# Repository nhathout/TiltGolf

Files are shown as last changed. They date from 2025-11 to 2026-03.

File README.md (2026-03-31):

<p align="center">
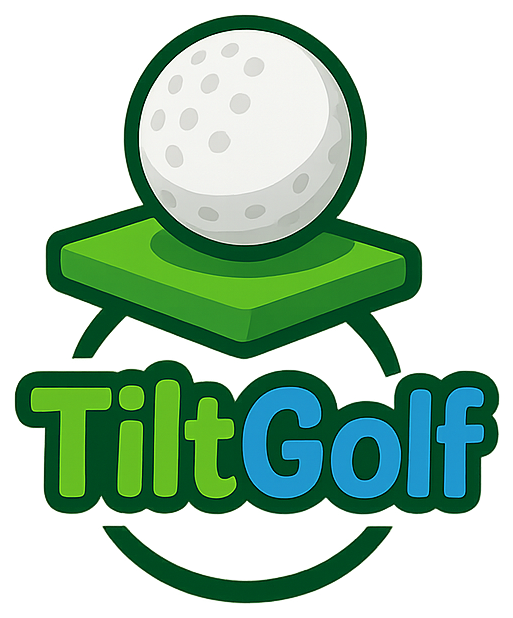
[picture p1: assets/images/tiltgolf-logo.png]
TiltGolf logo
  
</p>

TiltGolf is a tilt-controlled golf game that runs on a BeagleBone with an attached LCD. An IMU senses tilt and a kernel-space driver streams those readings to the Qt game. The UI presents arcade-style menus and levels, while the physics layer keeps the golf ball rolling realistically around the different levels.

## Demo
<p align="center">
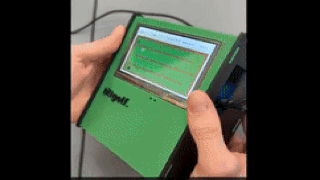
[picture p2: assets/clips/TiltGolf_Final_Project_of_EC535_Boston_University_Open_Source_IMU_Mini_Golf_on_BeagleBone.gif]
TiltGolf gameplay demo
  
</p>

<p align="center">
  <a href="assets/clips/TiltGolf%20%E2%80%94%20Final%20Project%20of%20EC535%20%40%20Boston%20University%20_%20Open-Source%20IMU%20Mini%20Golf%20on%20BeagleBone.mp4">View the full MP4 demo</a>
</p>

## Project Links
- YouTube demo: https://www.youtube.com/watch?v=vEOcKTJfxNo
- Final report (PDF): https://github.com/nhathout/TiltGolf/blob/main/tiltgolf-final-report.pdf
- Progress presentation (PDF): https://github.com/nhathout/TiltGolf/blob/main/assets/progress-presentation/TiltGolf_%20Project%20Progress.pdf

## Hardware & Software Stack
- **BeagleBone Black + LCD cape** – what the game renders on.
- **Custom IMU module** – `IMU.*` and the kernel driver provide filtered tilt angles.
- **Qt 5 widgets UI** – `main.cpp`, `MainWindow`, `MenuScreen`, and `GameScreen` deliver the UX optimized for touch.
- **Physics layer** – `PhysicsEngine.*`, `GameController.*`, and `GameView.*` synchronize IMU input with Box2D-style ball motion.

## Building the Qt Application
The checked-in `Makefile` was generated by `qmake` for the EC535 BeagleBone cross toolchain. If you are on that toolchain:

```bash
cd tiltgolf
make          # uses qmake-generated rules and the arm-linux-g++ compiler
```

For native desktop experimentation you can regenerate host build files:

```bash
cd tiltgolf
qmake tiltgolf.pro
make
./tiltgolf    # runs the Qt UI on your workstation
```

> ℹ️  Ensure Qt 5.15 (or later) development packages and a C++17-capable compiler are installed.

## Prebuilt BeagleBone Binary
- `tiltgolf/tiltgolf_final` is the ready-to-run executable for the BeagleBone + IMU + LCD setup if you prefer not to run `make`.
- Copy to the board and run it.

## Box2D Test (runs on Mac)
The `Box2DTest.cpp` file is a lightweight SFML window that drives a Box2D world for tuning forces, damping, and collisions before pushing to hardware.

### Prerequisites
- Box2D 3.x headers/libraries available on your system (e.g., via package manager).
- SFML 2.5+ development packages (`sfml-graphics`, `sfml-window`, `sfml-system`).

### Build & Run the Test
```bash
mkdir -p build
g++ -std=c++17 tiltgolf/Box2DTest.cpp -I/usr/include -o build/Box2DTest \
    $(pkg-config --cflags --libs sfml-graphics sfml-window sfml-system box2d)

./build/Box2DTest
```

## Screens & Levels
<table>
  <tr>
    <td>Main menu</td>
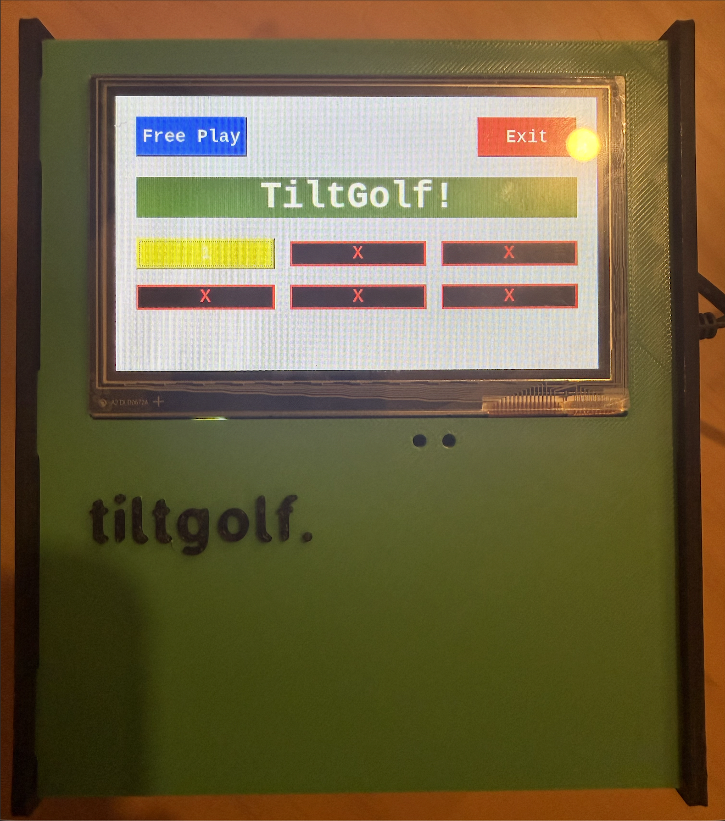
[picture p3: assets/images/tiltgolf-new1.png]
TiltGolf menu mock
    <td></td>
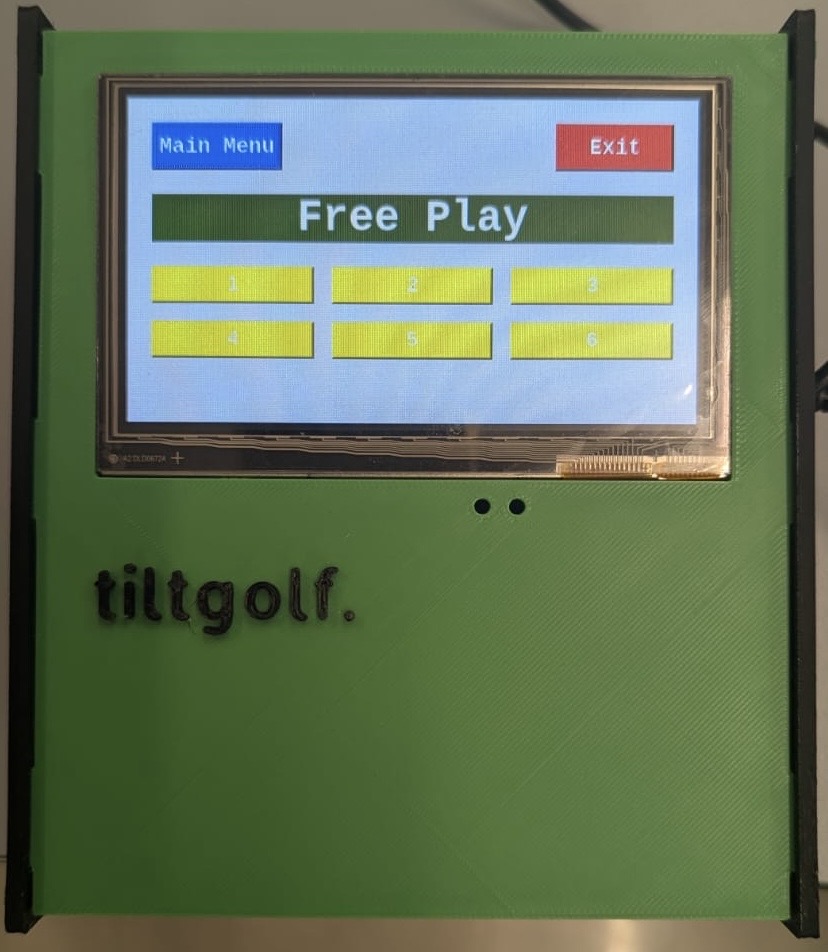
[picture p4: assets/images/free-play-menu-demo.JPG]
Free play menu
    <td></td>
  </tr>
  <tr>
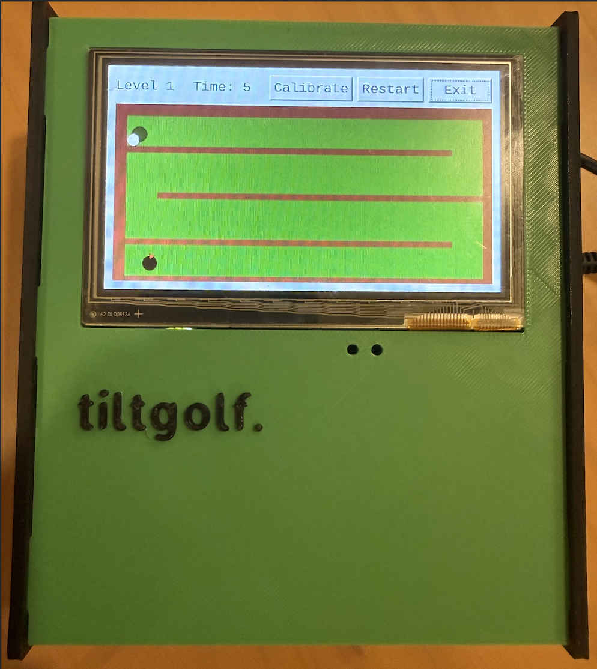
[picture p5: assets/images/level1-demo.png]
Level 1
    <td></td>
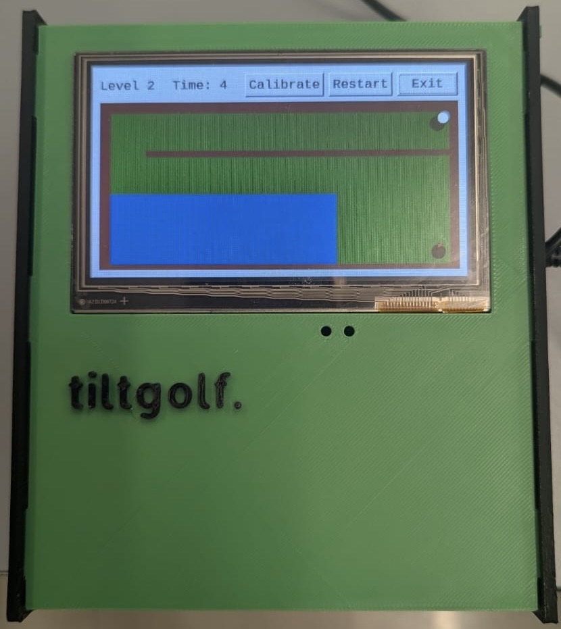
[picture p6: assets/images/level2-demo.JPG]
Level 2
    <td></td>
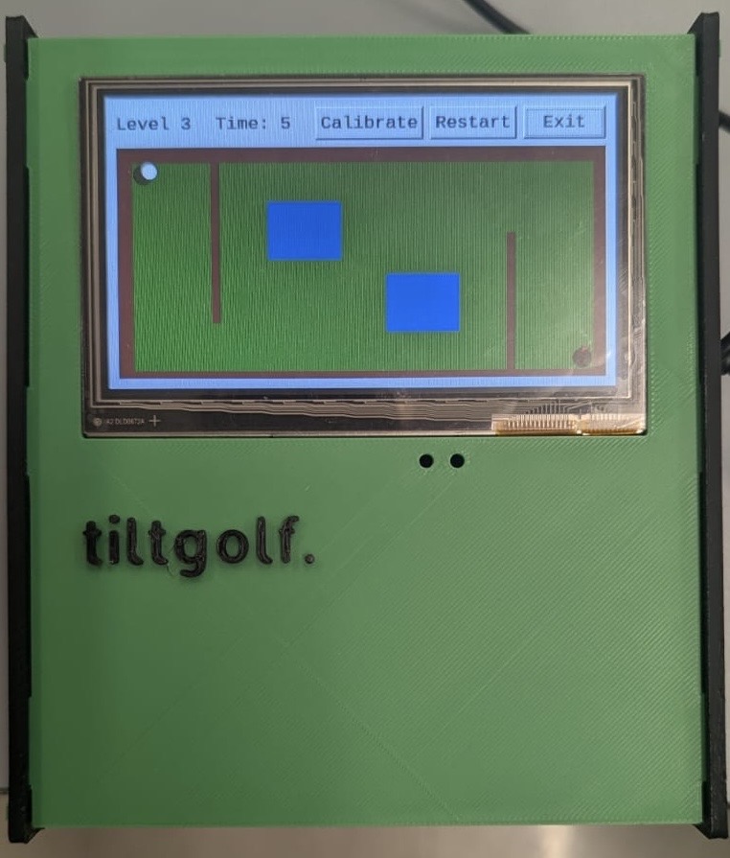
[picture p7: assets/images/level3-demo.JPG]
Level 3
    <td></td>
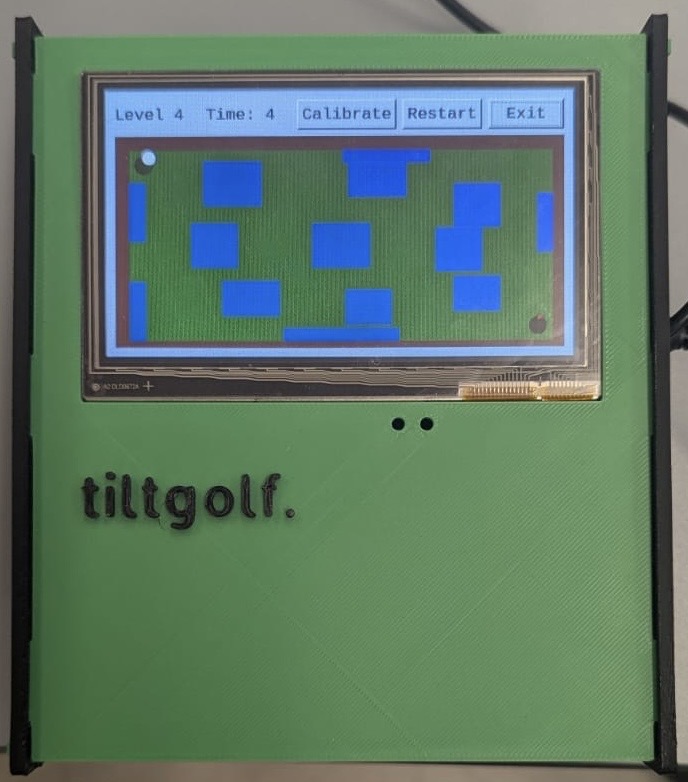
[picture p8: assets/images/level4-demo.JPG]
Level 4
    <td></td>
  </tr>
  <tr>
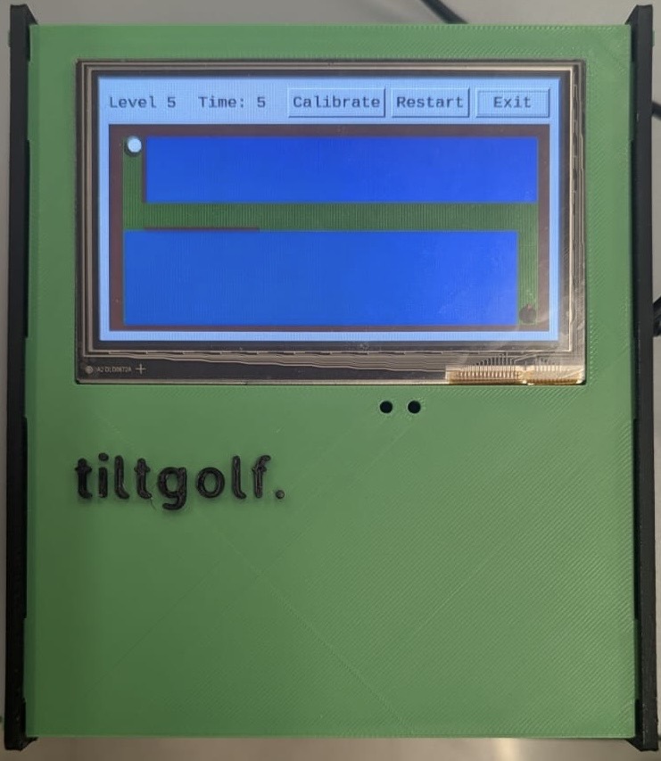
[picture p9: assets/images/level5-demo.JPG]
Level 5
    <td></td>
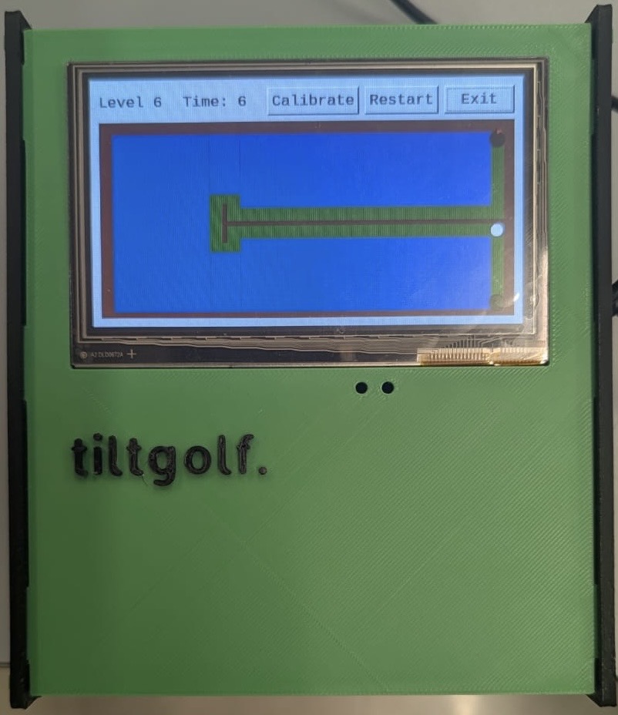
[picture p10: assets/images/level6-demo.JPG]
Level 6
    <td></td>
  </tr>
</table>

## Hardware
<table>
  <tr>
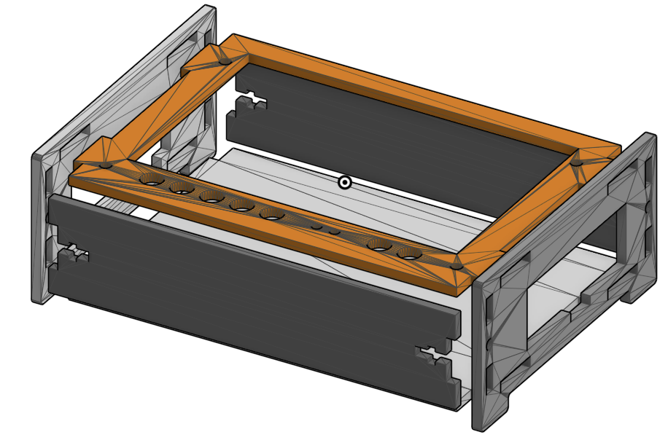
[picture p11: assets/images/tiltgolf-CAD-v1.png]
TiltGolf CAD v1
    <td></td>
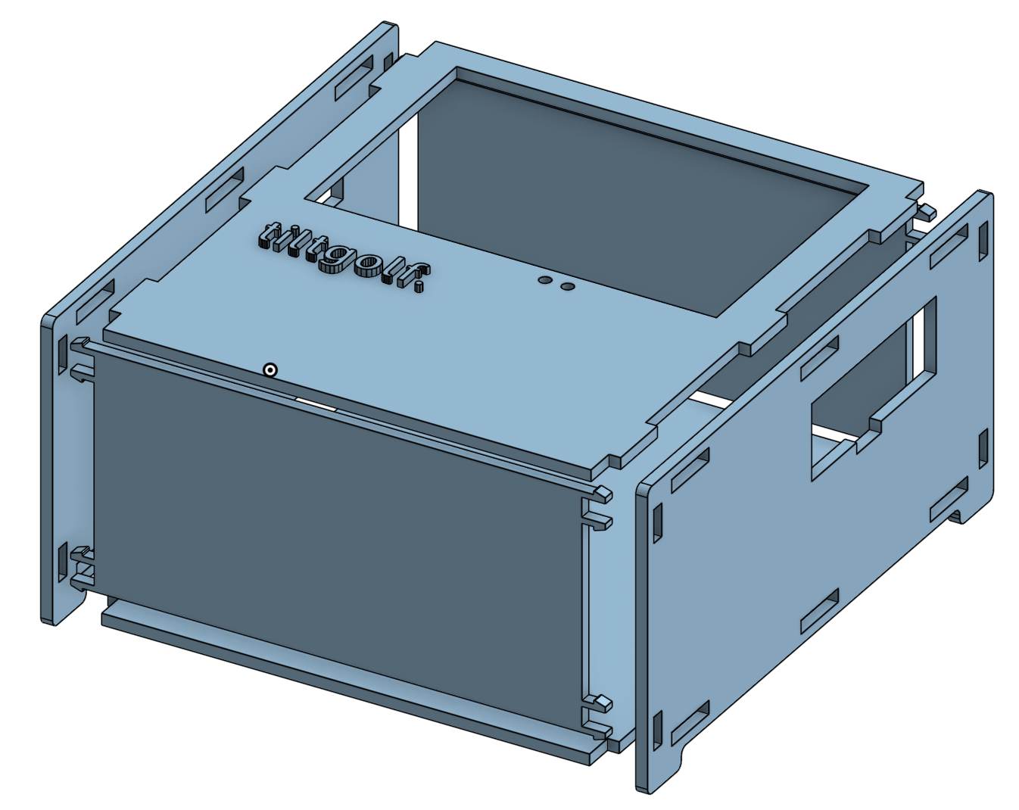
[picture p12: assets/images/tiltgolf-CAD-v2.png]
TiltGolf CAD v2
    <td></td>
  </tr>
</table>

## Physics Engine Test
<p>
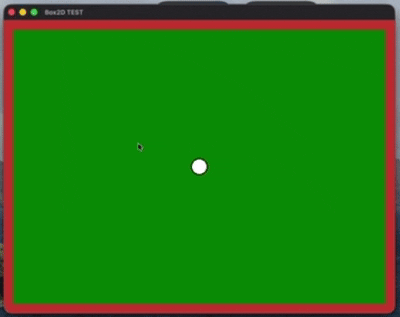
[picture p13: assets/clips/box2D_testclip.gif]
Box2D physics engine test
  
</p>

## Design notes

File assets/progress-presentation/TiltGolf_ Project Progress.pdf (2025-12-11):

# TiltGolf: Tilt-Controlled Golf Game on a BeagleBone

## Team TiltGolf

## Noah Hathout (nhathout@bu.edu), Bennett Taylor (betaylor@bu.edu), Skanda Nadig(skandan@bu.edu)

## Motivation and Project Idea

- Problem: Create a fun, interactive game that uses simulated real-world physics without relying on buttons, joysticks, or keyboard inputs. We also want to make this module as polished as possible with a custom 3D printed enclosure and fun level design.
- Who Cares? Students and/or instructors in embedded systems could use the game as a fun demo of kernel modules and divers + real-time graphics and simulated physics. Kids would also have a lot of fun playing a “GameBoy”-like game that is both challenging and fulfilling.
- Main Project Idea:
- Golf game running entirely on Breaglebone + LCD cape; 3D printed handheld enclosure with built-in IMU for tilt sensing; Qt UI + physics engine that make gameplay smooth and realistic.

## 3D Printed Enclosure Inspiration

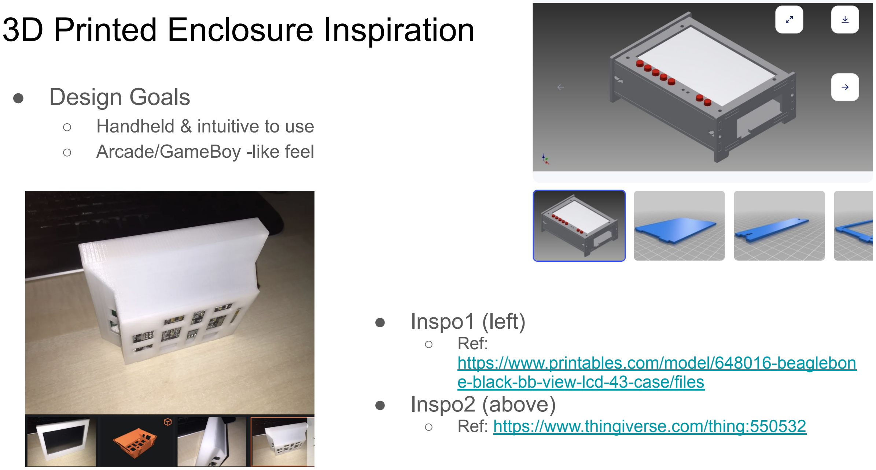
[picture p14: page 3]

- Design Goals
- Handheld & intuitive to use
- Arcade/GameBoy -like feel
- Inspo1 (left)
- Ref:
https://www.printables.com/model/648016-beaglebone-black-bb-view-lcd-43-case/files (https://www.printables.com/model/648016-beaglebone-black-bb-view-lcd-43-case/files)
- Inspo2 (above)
- Ref: https://www.thingiverse.com/thing:550532

## Project Description

- Summary:
TiltGolf is a tilt-controlled golf game that runs on a BeagleBone Black with an attached LCD cape. Also in the enclosure will be an IMU that senses the device’s tilt. This tilt will be filtered in the kernel-space and fed to the Qt-based game. The layer that takes care of the physics engine is based on Box2D with realistic physics and acceleration properties so that the ball rolls, slows down, and bounces off walls realistically as the player tils the device. QT is used to handle menuing, LCD user input, and rendering the Box2D golf simulation.

## System Architecture

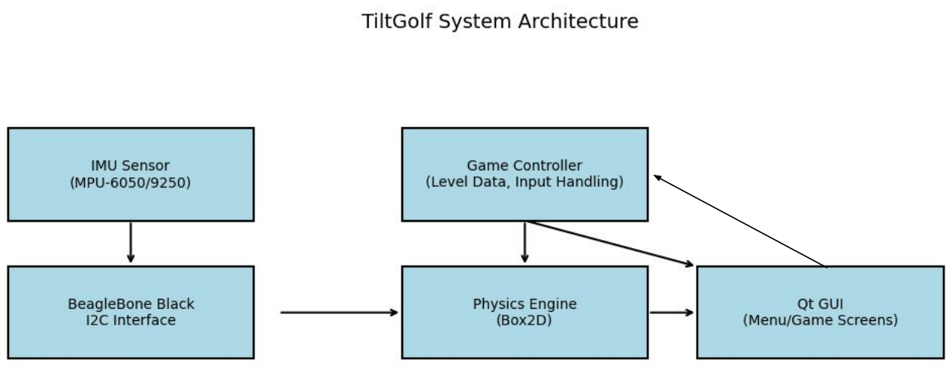
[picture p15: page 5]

5. Physics Engine
a. Box2D used for realistic ball movement and collision detection
b. Physics engine updates ball state each frame
c. Integrated into the game binary (statically linked)

## System Components

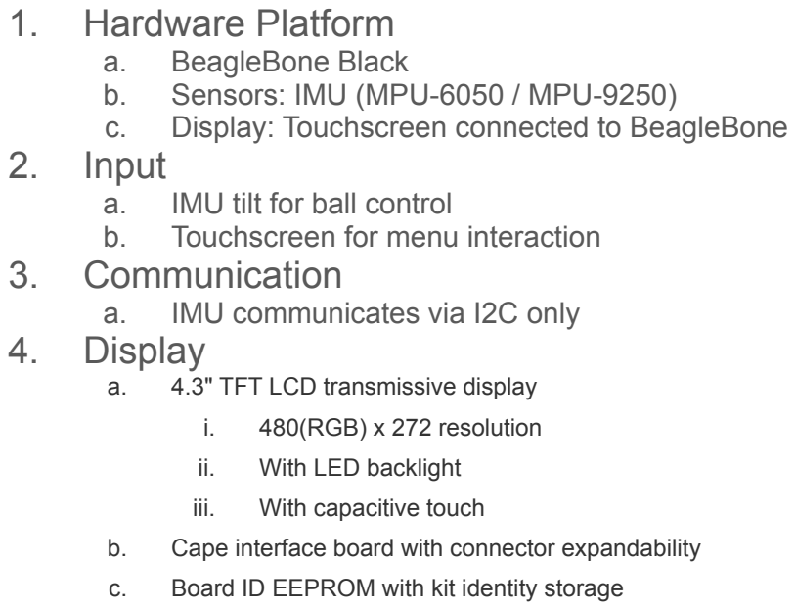
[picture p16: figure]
1. Hardware Platform; a. BeagleBone Black b. Sensors: IMU (MPU-6050 / MPU-9250); 2. Input; a. IMU tilt for ball control b. Touchscreen for menu interaction 3. Communication; a. IMU communicates via I2C only 4. Display; a. 4.3" TFT LCD transmissive display; i. 480(RGB) x 272 resolution; With LED backlight; iii.; With capacitive touch

c. Display: Touchscreen connected to BeagleBone
b. Cape interface board with connector expandability
c. Board ID EEPROM with kit identity storage

## System Components

5. Physics Engine
a. Box2D used for realistic ball movement and collision detection
b. Physics engine updates ball state each frame
c. Integrated into the game binary (statically linked)
6. Rendering
a. Qt GUI for all game screens and visual updates
b. Game loop:
i. Choose level → Start simulation → Read IMU → Update Physics → Render Screen → Repeat → Exit or Restart
7. Output / Audio
a. Visual output only (Qt GUI)
b. No audio output

## Milestones, timeline, and breakdown of tasks

- Creation of level data, game loop, and leaderboard
- Assigned to: Bennett Taylor
- Complete by: December 3rd
- Progress: Level start and restart have been completed
- Leaderboard and separate users is “nice to have”
- Integration of level data and Box2D simulation
- Assigned to: Noah Hathout
- Complete by: December 6th
- Progress: Box2D simulation framework has been established
- Integration of menuing and Box2D simulation rendering
- Assigned to: Bennett Taylor
- Complete by: November 31st
- Progress: Menuing and Box2D rendering have both been completed
- Integration of IMU output and Box2D simulation
- Assigned to: Skanda Nadig
- Complete by: December 3rd
- Progress: IMU output is being read and Box2D simulation is in working order

Work Package | Nov | Nov | Nov | Nov | Nov | Dec | Dec | Dec
1.0. Planning | Design | Implementation | | Test, Debug, Improve
2.0. Screen Design | Design | Implementation | | Test, Debug, Improve
3.0. Sensor testing | Tech. Req. Definition | Test, Debug, Improve
4.0. Hardware integration | Design | Implement logic | | Test, Debug, Improve
5.0 Game Physics Box2D | Plan & Design | Implement logic | Integrate with screen & hardware
6.0 Report | | Structure | | Write-up Editing
7.0. Presentation | | | | Structure | Content

## Box2D Physics Engine Test

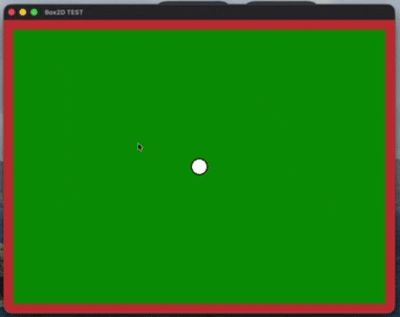
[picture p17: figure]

Here is a clip showing a golf
ball working with the Box2D
physics engine in a simple 4-wall map. This was our
proof-of-concept (running on a Mac with arrow key inputs) that now allows us to use the
physics on the hardware and create new levels and maps.

## IMU sensor(MPU-6050 / MPU-9250)

1. Purpose:
a. Measures device orientation (tilt along X, Y, Z axes)
b. Provides accelerometer and gyroscope data for game input
2. Connection:
a. Connected to BeagleBone Black via I2C interface
3. Data Acquisition:
a. Registers used:
i. Accelerometer: ACCEL_XOUT_H/L, ACCEL_YOUT_H/L, ACCEL_ZOUT_H/L
ii. | Gyroscope: GYRO_XOUT_H/L, GYRO_YOUT_H/L, GYRO_ZOUT_H/L
iii. | Configuration: PWR_MGMT_1, CONFIG, etc.
4. Reading values:
a. Using I2C commands (i2cget, i2c-tools) or hexdump for debugging
b. Example: i2cget -y 1 0x68 0x3B to read ACCEL_X register

## IMU sensor Pin layout

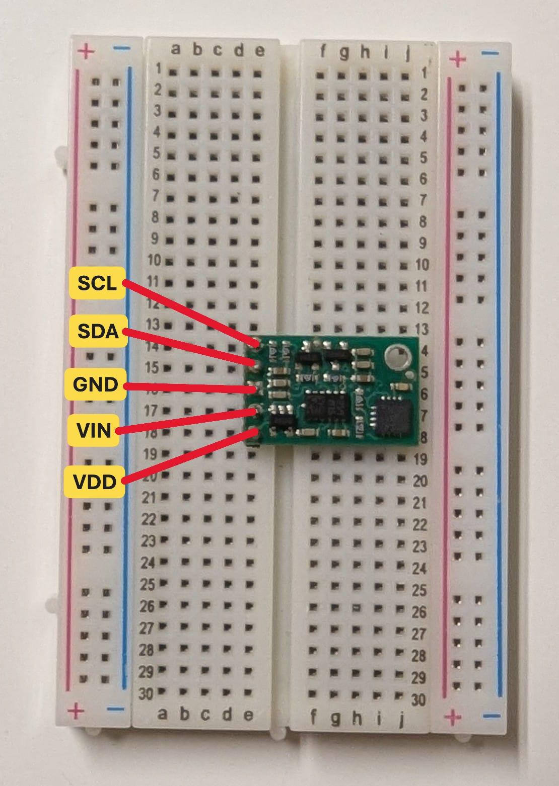
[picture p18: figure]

- SCL – I2C clock line, synchronizes data between IMU and BBB. Connected to P9_19 of Beaglebone
- SDA – I2C data line, carries sensor readings to the BeagleBone. Connected to P9_20 of Beaglebone
- GND – Ground reference for IMU and BeagleBone.
Connected to P8_2 of Beaglebone
- VIN – Input voltage to power the IMU (e.g., 3.3V or 5V). Connected to P9_4 of Beaglebone
- VDD – Logic supply voltage for the IMU’s internal circuitry. Connected to P9_4 of Beaglebone

## IMU sensor circuit connections

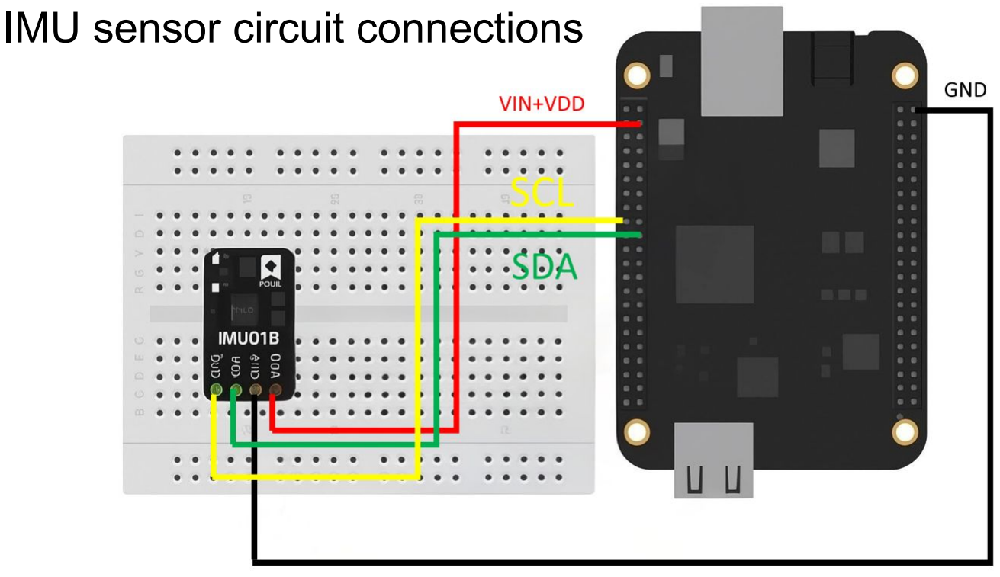
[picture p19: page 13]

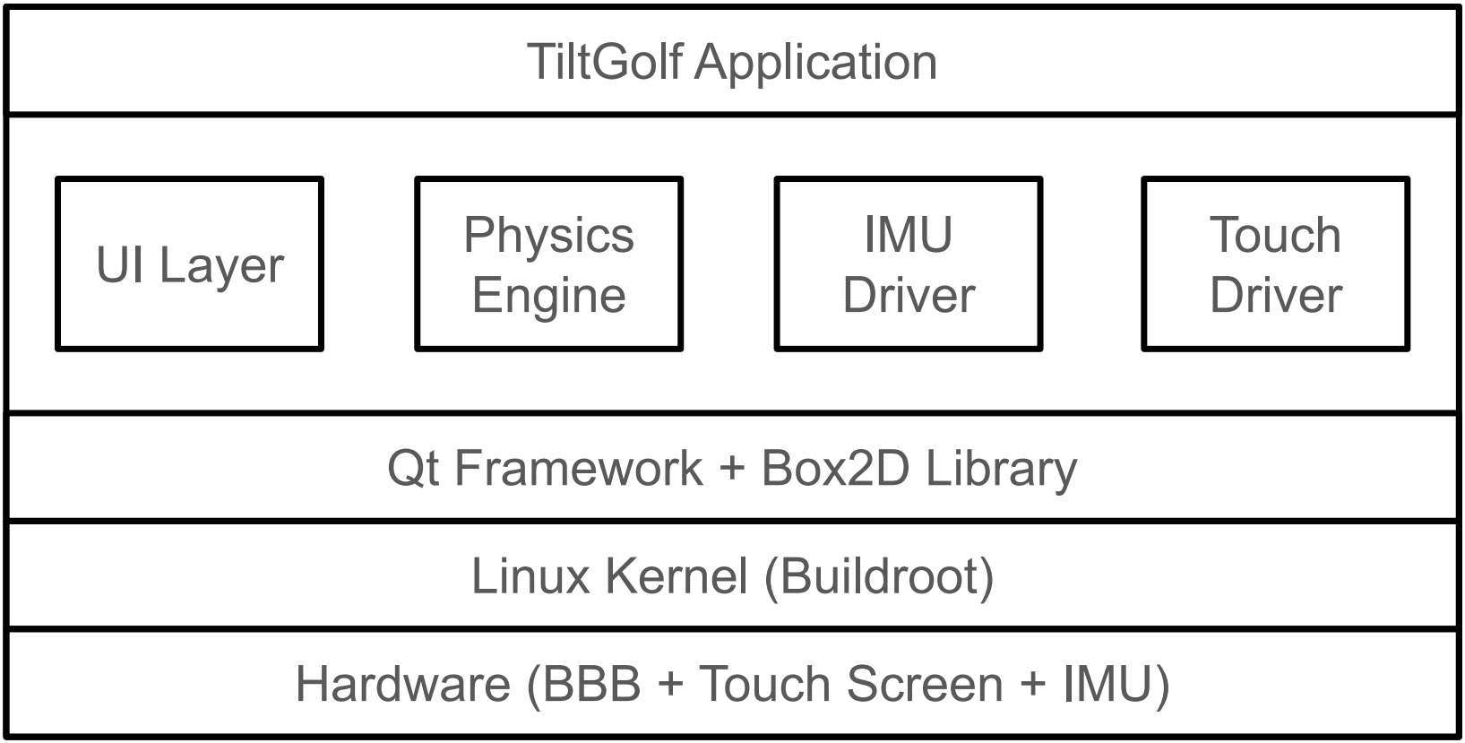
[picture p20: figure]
TiltGolf Application; UI Layer; Physics; Engine; IMU Driver; Touch Driver; Hardware (BBB + Touch Screen + IMU); Linux Kernel (Buildroot); Qt Framework + Box2D Library

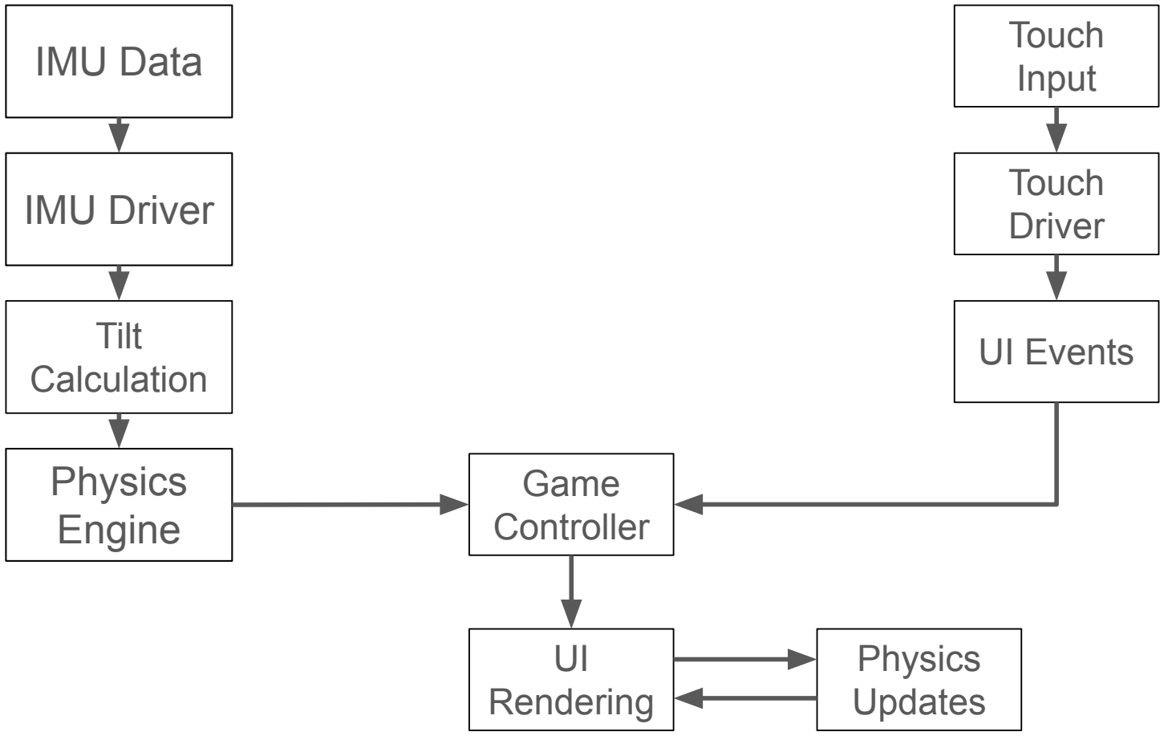
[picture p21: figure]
Touch Driver; Touch Input IMU Data; IMU Driver; Tilt Calculation; Physics Engine; Game Controller; UI Events; UI Rendering; Physics Updates

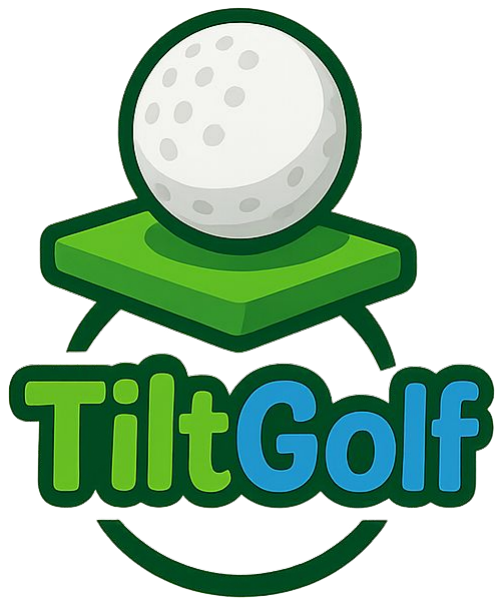
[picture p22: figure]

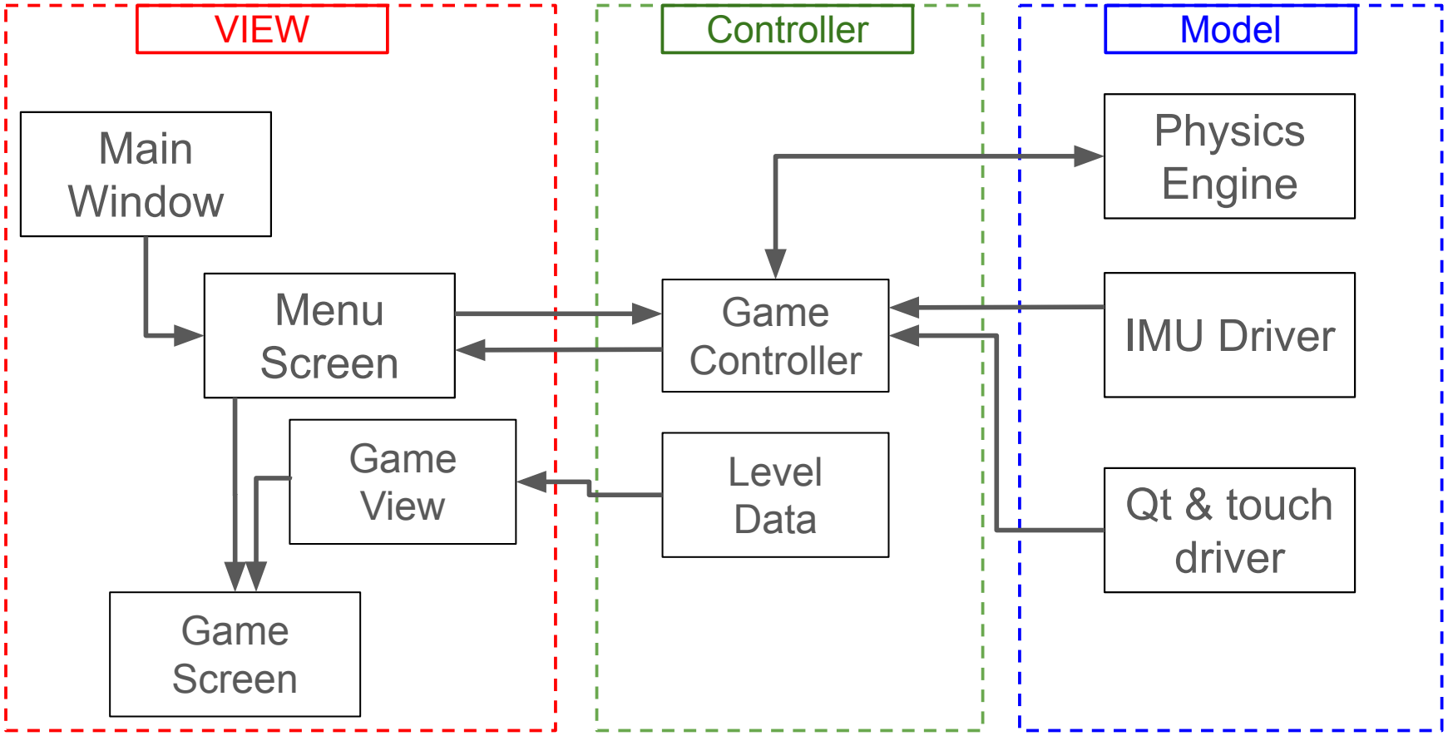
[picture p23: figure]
Main Window; Menu Screen; Game Screen; Physics Engine; Game; Controller; IMU Driver; Qt & touch driver; VIEW; Model; Game View; Level Data

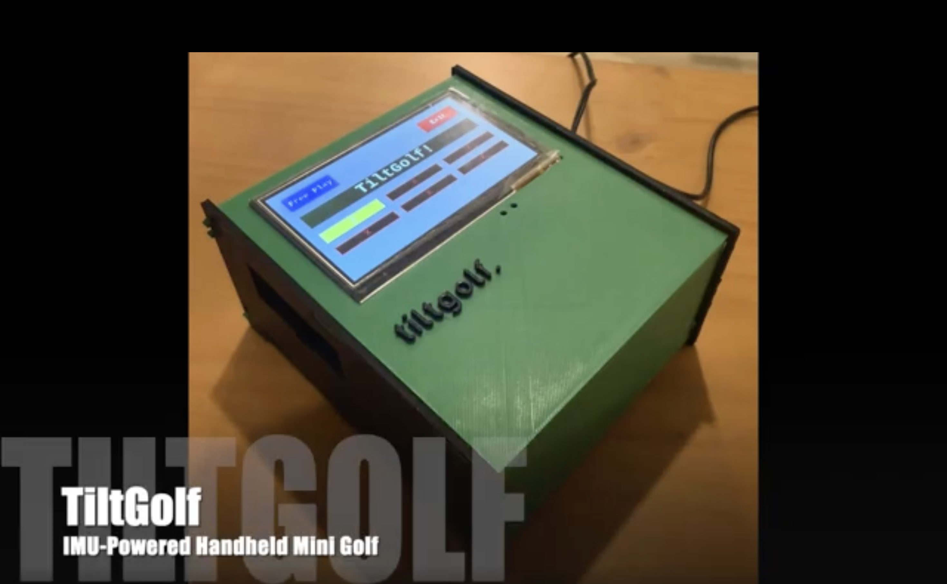
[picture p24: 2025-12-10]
assets/images/video-thumbnail.png

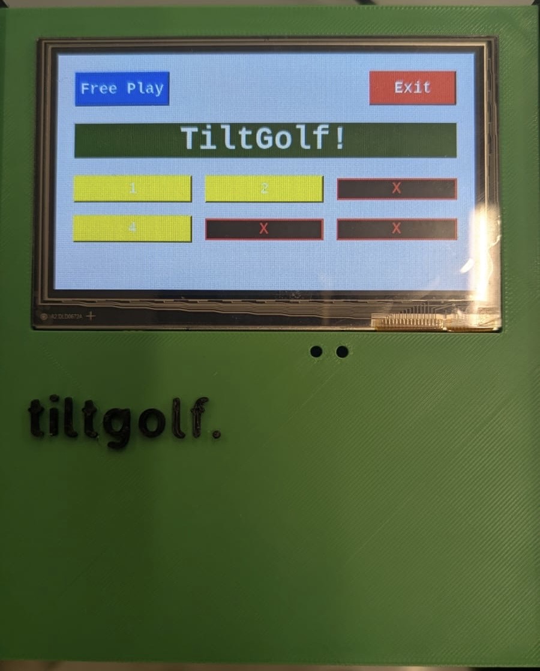
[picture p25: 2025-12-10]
assets/images/main-menu-demo.JPG

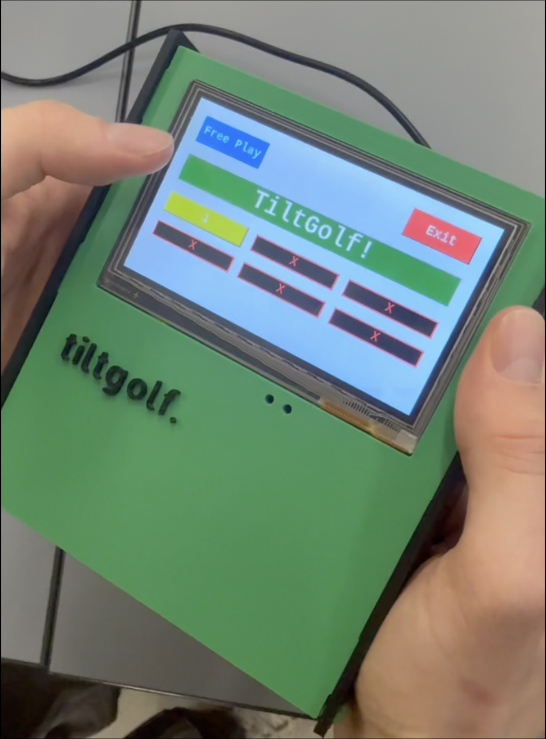
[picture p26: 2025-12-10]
assets/images/tiltgolf-menu.png

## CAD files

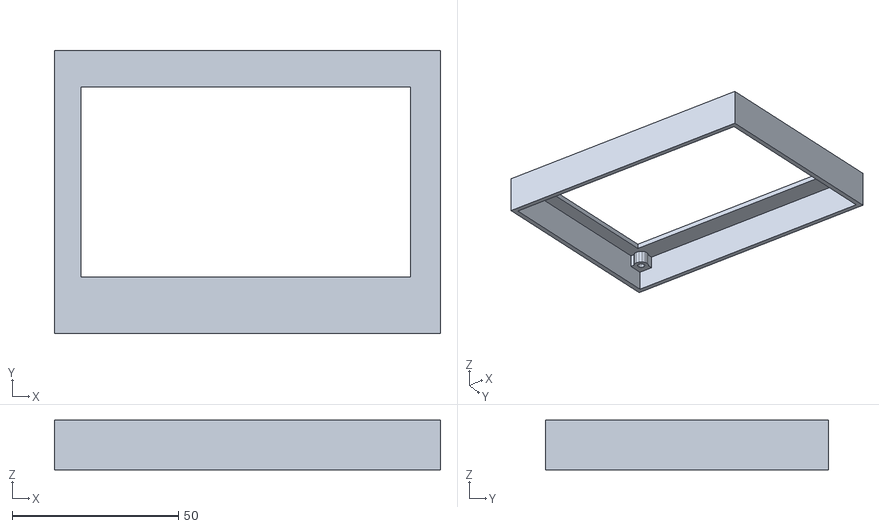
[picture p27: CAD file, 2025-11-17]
assets/housing/inspiration/beaglebone-black-bb-view-lcd-43-case-model_files/bbb_case_front_lcd_mount.stl
116.0 x 85.0 x 15.0

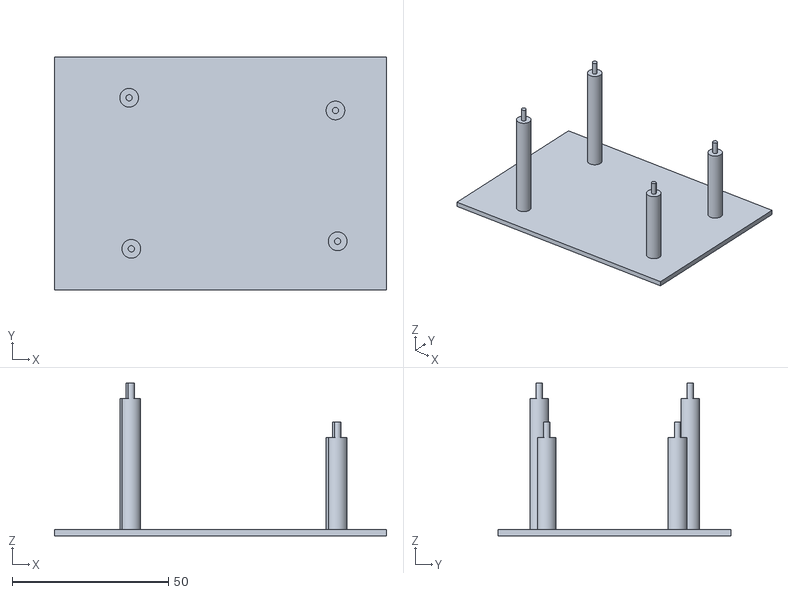
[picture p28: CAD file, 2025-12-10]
assets/housing/v2/bbbholder.stl
106.4 x 74.6 x 49.0

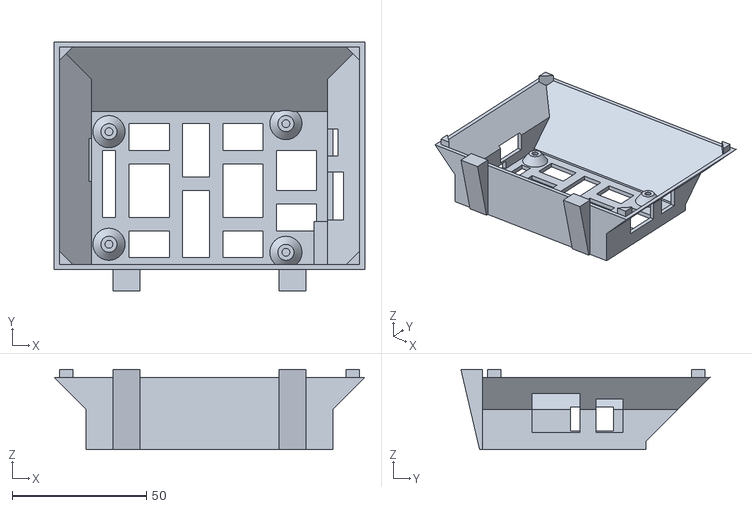
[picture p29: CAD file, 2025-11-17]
assets/housing/inspiration/beaglebone-black-bb-view-lcd-43-case-model_files/bbb_case_back_board_mount.stl
116.0 x 93.0 x 30.0

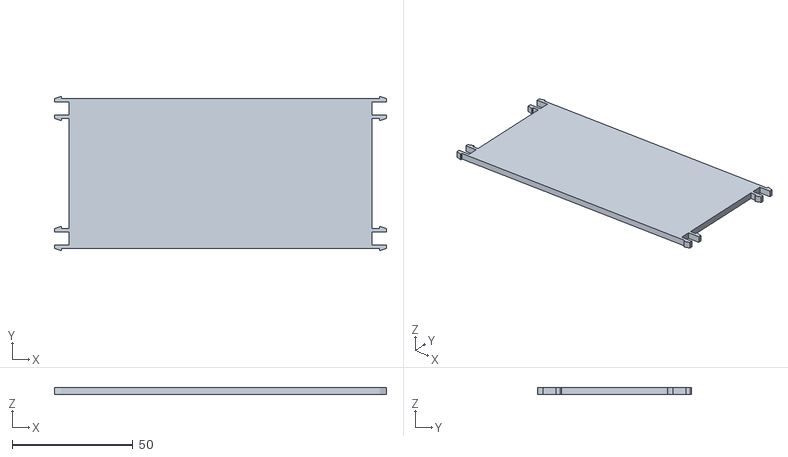
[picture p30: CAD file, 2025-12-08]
assets/housing/v2/topbottomcovernew.stl
137.4 x 63.8 x 3.00

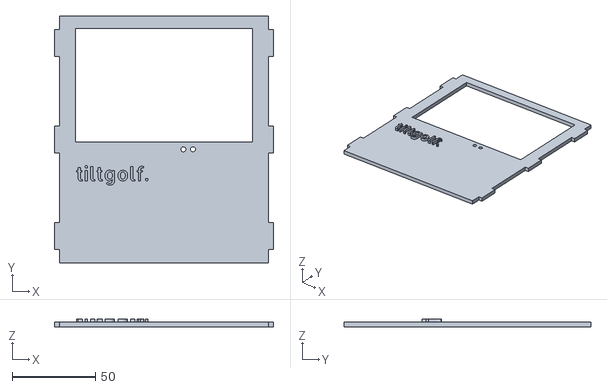
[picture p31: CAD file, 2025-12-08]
assets/housing/v2/frontcovernew.stl
131.4 x 148.0 x 5.00

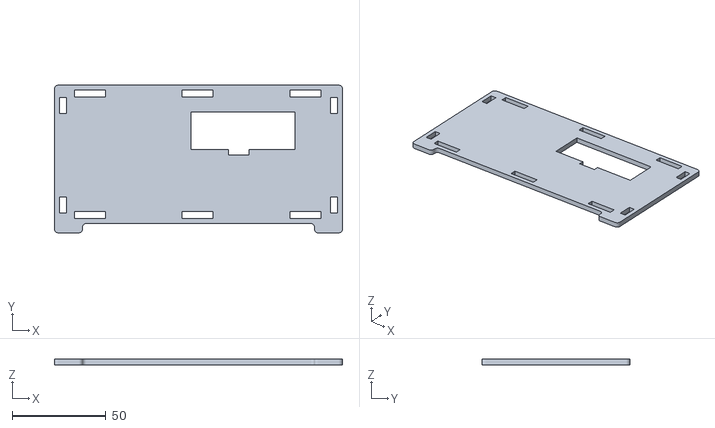
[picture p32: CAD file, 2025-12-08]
assets/housing/v2/leftcovernew.stl
154.0 x 79.0 x 3.00

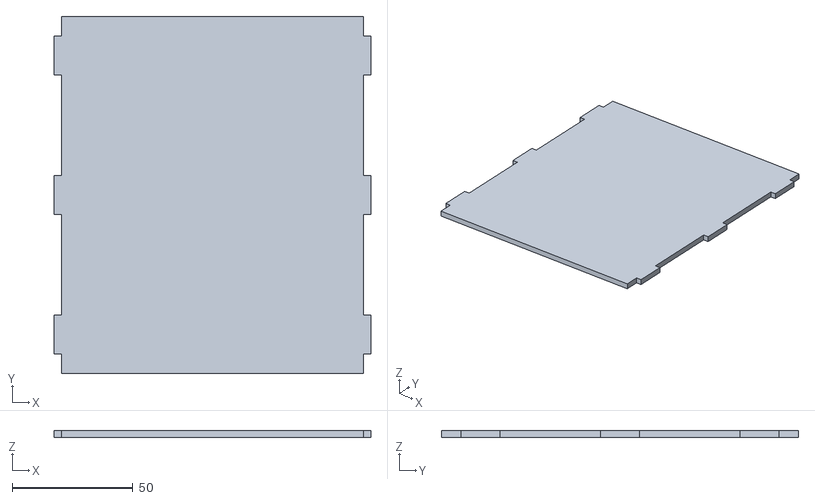
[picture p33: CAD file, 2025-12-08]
assets/housing/v2/backcovernew.stl
131.4 x 148.0 x 3.00

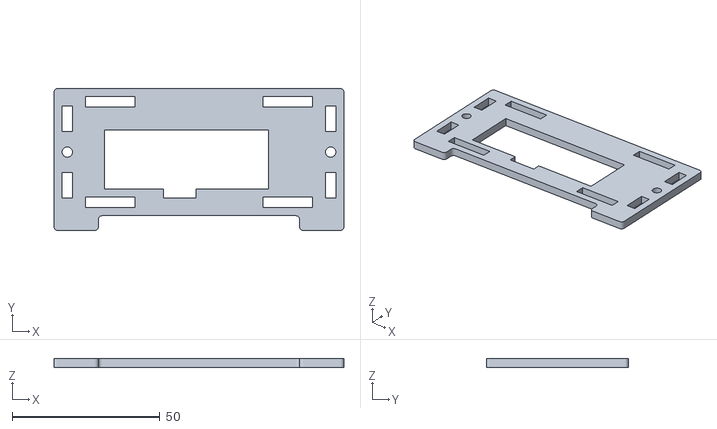
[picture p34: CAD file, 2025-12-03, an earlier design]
assets/housing/v1/LeftCover.stl
98.0 x 48.0 x 3.00

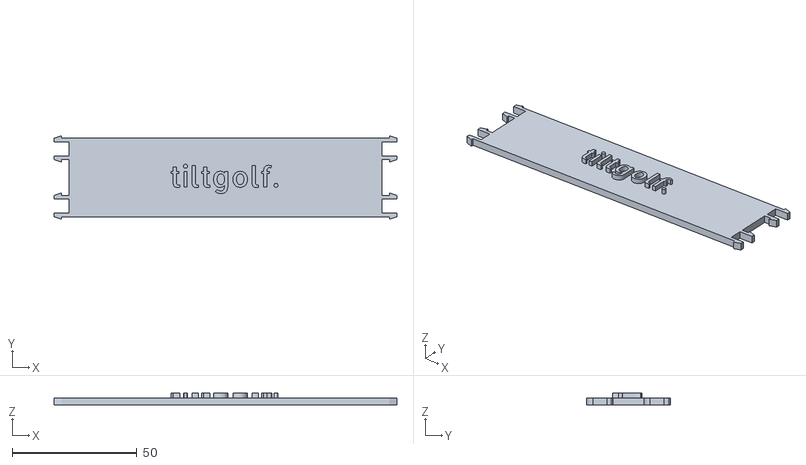
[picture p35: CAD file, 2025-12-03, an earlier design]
assets/housing/v1/topbottomcovernew-text.stl
137.4 x 33.5 x 5.00

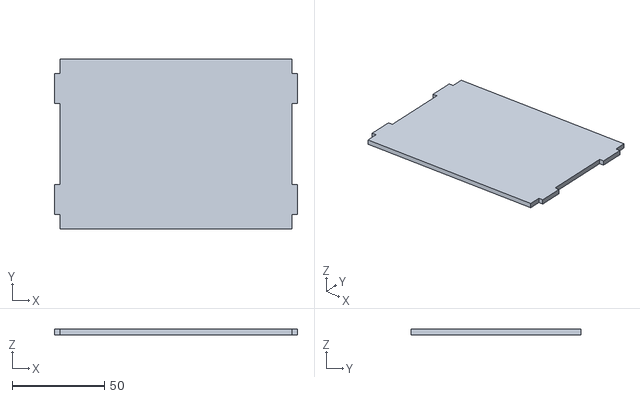
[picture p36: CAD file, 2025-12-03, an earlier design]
assets/housing/v1/BackCover.stl
131.4 x 92.0 x 3.00

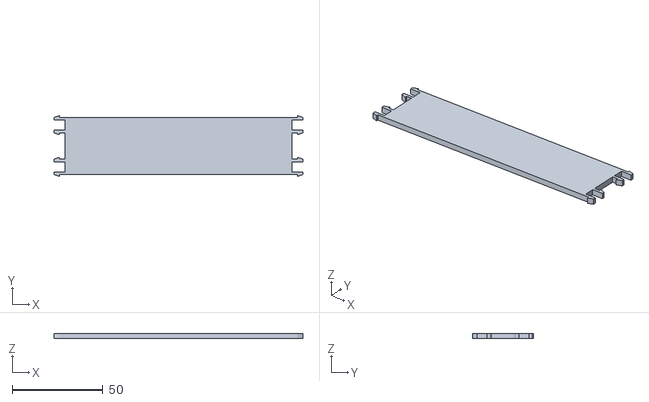
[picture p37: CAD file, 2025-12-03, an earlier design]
assets/housing/v1/topbottomcovernew.stl
137.4 x 33.5 x 3.00

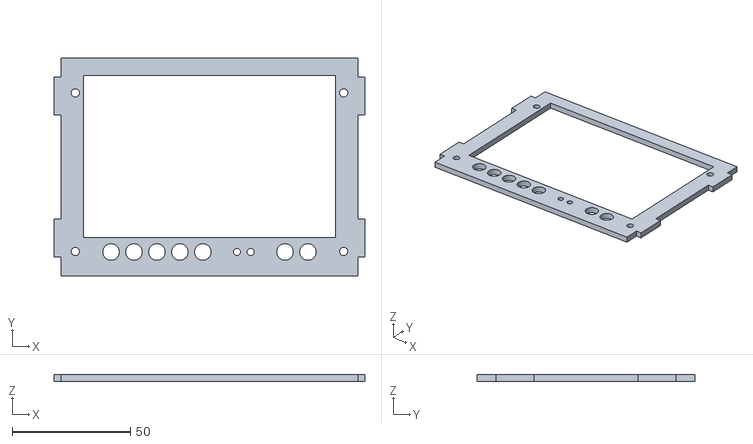
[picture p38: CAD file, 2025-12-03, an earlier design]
assets/housing/v1/FrontCover.stl
131.4 x 92.0 x 3.00

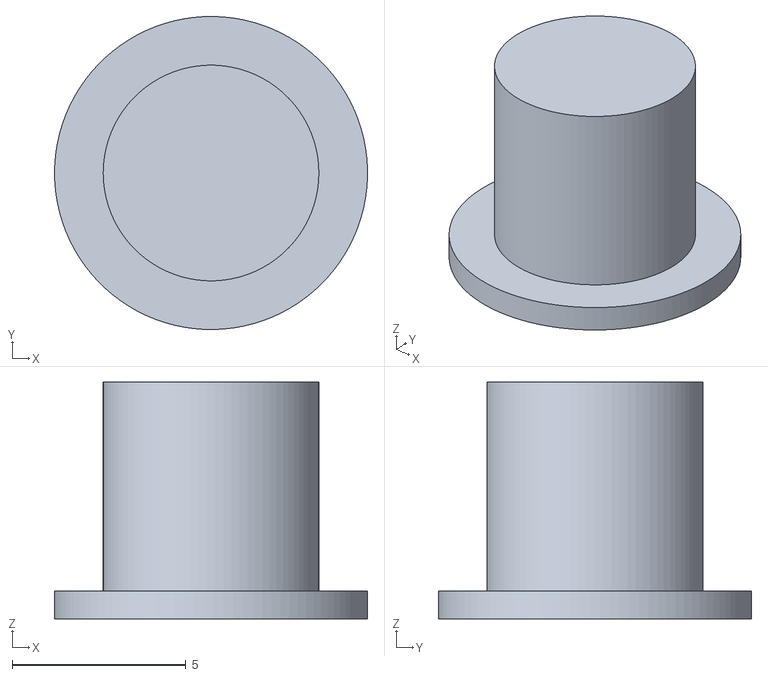
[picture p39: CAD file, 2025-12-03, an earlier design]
assets/housing/v1/Button.stl
9.00 x 9.00 x 6.80

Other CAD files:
assets/housing/v2/rightcovernew.stl
assets/housing/v1/RightCover.stl

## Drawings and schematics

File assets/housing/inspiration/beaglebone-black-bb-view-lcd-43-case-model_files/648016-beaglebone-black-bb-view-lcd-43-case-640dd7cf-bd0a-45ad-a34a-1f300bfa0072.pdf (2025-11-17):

# Beaglebone Black BB-View LCD 4.3

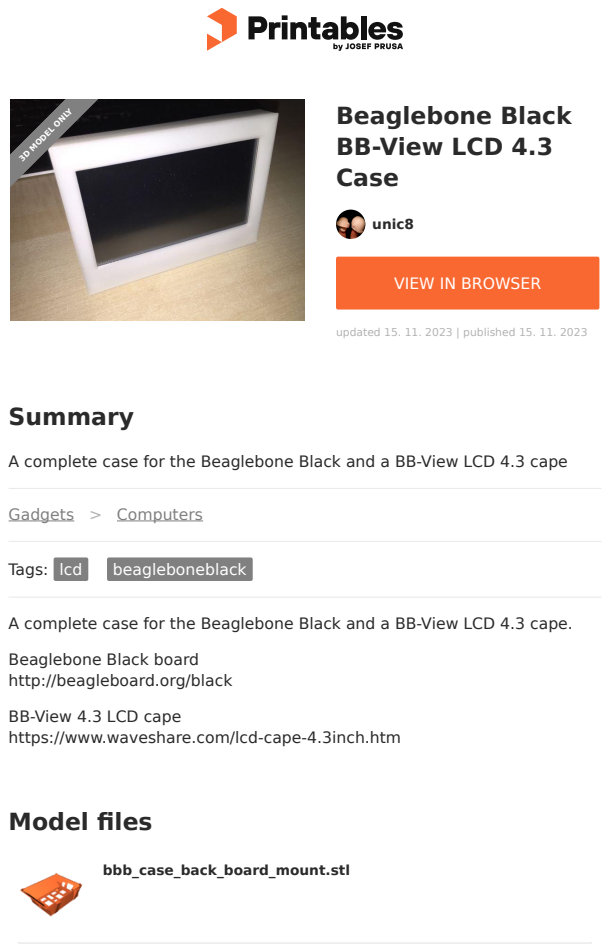
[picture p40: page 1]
Model files; Summary; Gadgets; Computers; Tags: lcd; beagleboneblack; unic8; Case; updated 15. 11. 2023 | published 15. 11. 2023; bbb_case_back_board_mount.stl; 3D MODEL ONLY

VIEW IN BROWSER (https://printables.com/model/648016-beaglebone-black-bb-view-lcd-43-case)

A complete case for the Beaglebone Black and a BB-View LCD 4.3 cape

A complete case for the Beaglebone Black and a BB-View LCD 4.3 cape.

Beaglebone Black board
http://beagleboard.org/black

BB-View 4.3 LCD cape
https://www.waveshare.com/lcd-cape-4.3inch.htm

# License

This work is licensed under a
Creative Commons (4.0 International License)

Attribution—Noncommercial—Share Alike (http://creativecommons.org/licenses/by-nc-sa/4.0/)

✖ | Sharing without ATTRIBUTION
✔ | Remix Culture allowed
✖ | Commercial Use
✖ | Free Cultural Works
✖ | Meets Open Definition

bbb_case_front_lcd_mount.stl

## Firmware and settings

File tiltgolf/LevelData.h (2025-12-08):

#ifndef LEVELDATA_H
#define LEVELDATA_H

#include <vector>
#include <algorithm>
#include <cmath>
#include "box2d/box2d.h"

// Conversion factor: 15 pixels = 1 meter (compile-time constant)
const float PPM = 15.0f;

struct WallDef {
    b2Vec2 position; // Center position in meters
    b2Vec2 size;     // Half-width and Half-height in meters
};

struct MovingWaterDef {
    b2Vec2 basePosition; // nominal center position (meters)
    b2Vec2 position;     // current center position (meters), updated each step
    b2Vec2 size;         // Half-width and Half-height in meters
    float amplitude;     // vertical oscillation amplitude (meters)
    float speed;         // oscillation speed (radians per second)
    float phase;         // current phase (radians)
    float direction;     // 1.0 or -1.0 to invert motion
};

struct LevelConfig {
    int id;
    b2Vec2 ballStartPos;
    b2Vec2 holePos;
    float holeRadius;
    std::vector<WallDef> walls;
    std::vector<WallDef> water;
    std::vector<MovingWaterDef> movingWater;
    float width;  // World width in meters
    float height; // World height in meters
};

class LevelData {
public:
    static LevelConfig getLevel(int id) {
        LevelConfig level;
        level.id = id;

        // Define World Size (meters)
        level.width = 31.0f;
        level.height = 15.0f;

        // Default hole size (meters)
        level.holeRadius = 0.6f; // slightly larger than the 0.5m ball radius

        // Wall thickness (half-size in meters).
        float wallThick = 0.5f;

        // Clear any existing geometry (safety)
        level.walls.clear();
        level.water.clear();
        level.movingWater.clear();

        // --- Boundary walls (placed fully inside the world) ---
        // Top wall: center at y = wallThick, spans full width
        level.walls.push_back({b2Vec2(level.width * 0.5f, wallThick), b2Vec2(level.width * 0.5f, wallThick)});

        // Bottom wall: center at y = height - wallThick, spans full width
        level.walls.push_back({b2Vec2(level.width * 0.5f, level.height - wallThick), b2Vec2(level.width * 0.5f, wallThick)});

        // Left wall: center at x = wallThick, spans full height
        level.walls.push_back({b2Vec2(wallThick, level.height * 0.5f), b2Vec2(wallThick, level.height * 0.5f)});

        // Right wall: center at x = width - wallThick, spans full height
        level.walls.push_back({b2Vec2(level.width - wallThick, level.height * 0.5f), b2Vec2(wallThick, level.height * 0.5f)});

        // --- Per-level placement ---
        if (id == 2)
        {
            // Level 2: top-right start, single horizontal bar near the top, large water region bottom-left, hole bottom-right.
            float margin = 1.5f;
            level.ballStartPos.Set(level.width - wallThick - margin, wallThick + margin); // top-right
            level.holePos.Set(level.width - wallThick - margin, level.height - wallThick - margin); // bottom-right

            // Horizontal bar spanning to the right wall
            float barHalfThickness = 0.25f;
            float leftGap = 4.0f; // leave some gap on the left
            float barHalfWidth = (level.width - wallThick - leftGap) * 0.5f;
            float barCenterX = level.width - wallThick - barHalfWidth; // touching right wall
            float barY = level.height * 0.30f;
            level.walls.push_back({b2Vec2(barCenterX, barY), b2Vec2(barHalfWidth, barHalfThickness)});

            // Water: shorter in height (~40% of screen), bottom-left region
            float waterHalfW = level.width * 0.32f;        // ~64% width coverage
            float waterHalfH = level.height * 0.20f;       // 40% total height
            float waterCenterX = waterHalfW + wallThick;   // from left border inward
            float waterCenterY = level.height - wallThick - waterHalfH - 0.5f; // small margin from bottom
            level.water.push_back({b2Vec2(waterCenterX, waterCenterY), b2Vec2(waterHalfW, waterHalfH)});

            return level;
        }
        if (id == 3)
        {
            // Level 3: two moving water blocks oscillating opposite, start top-left, hole bottom-right.
            float margin = 1.2f;
            level.ballStartPos.Set(wallThick + margin, wallThick + margin); // near top-left
            level.holePos.Set(level.width - wallThick - margin, level.height - wallThick - margin); // bottom-right

            // small walls
            float slimHalfW = 0.25f;
            float leftHalfH = 5.0f;  
            float leftY = (wallThick * 2.0f) + leftHalfH; 
            float rightHalfH = 4.3f; 
            float rightY = (level.height - (wallThick * 2.0f)) - rightHalfH; 
            level.walls.push_back({b2Vec2(level.width * 0.20f, leftY), b2Vec2(slimHalfW, leftHalfH)});
            level.walls.push_back({b2Vec2(level.width * 0.80f, rightY), b2Vec2(slimHalfW, rightHalfH)});

            // Moving water blocks (vertical oscillation, opposite directions)
            float waterHalfW = 2.3f;
            float waterHalfH = 1.8f;
            float minCenterY = (wallThick * 2.0f) + waterHalfH;                  // touches top wall bottom edge
            float maxCenterY = (level.height - (wallThick * 2.0f)) - waterHalfH; // touches bottom wall top edge
            float baseY = (minCenterY + maxCenterY) * 0.5f;
            float amp = (maxCenterY - minCenterY) * 0.5f;     // reach top and bottom
            float speed = 1.0f;   // radians/sec (slow)

            MovingWaterDef left;
            left.basePosition.Set(level.width * 0.38f, baseY);
            left.position = left.basePosition;
            left.size.Set(waterHalfW, waterHalfH);
            left.amplitude = amp;
            left.speed = speed;
            left.phase = 0.0f;
            left.direction = 1.0f;

            MovingWaterDef right;
            right.basePosition.Set(level.width * 0.62f, baseY);
            right.position = right.basePosition;
            right.size.Set(waterHalfW, waterHalfH);
            right.amplitude = amp;
            right.speed = speed;
            right.phase = 0.0f; 
            right.direction = -1.0f;

            level.movingWater.push_back(left);
            level.movingWater.push_back(right);

            return level;
        }

        if (id == 4)
        {
            // Level 4: randomly placed static water rectangles; start top-left, hole bottom-right.
            // putting water near edges to prevent players hugging the edge.
            float margin = 1.5f;
            level.ballStartPos.Set(wallThick + margin, wallThick + margin); // top-left
            level.holePos.Set(level.width - wallThick - margin, level.height - wallThick - margin); // bottom-right

            // Scatter water rectangles; leave gaps wide enough for the ball in some spots
            auto addWater = [&](float cx, float cy, float hx, float hy) {
                level.water.push_back({b2Vec2(cx, cy), b2Vec2(hx, hy)});
            };
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

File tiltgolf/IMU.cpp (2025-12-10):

#include "IMU.h"
#include <fcntl.h>
#include <unistd.h>
#include <sys/ioctl.h>
#include <linux/i2c-dev.h>
#include <iostream>
#include <thread>
#include <chrono>

// I2C Configuration
#define I2C_DEVICE "/dev/i2c-2"
#define MAG_ADDR   0x1E

// Magnetometer Registers
#define CRA_REG_M  0x00 // Config A (Rate)
#define CRB_REG_M  0x01 // Config B (Gain)
#define MR_REG_M   0x02 // Mode
#define OUT_X_H_M  0x03 // Data Start

// Calibration averaging parameters
static const int CALIB_SAMPLE_COUNT = 6;
static const std::chrono::milliseconds CALIB_SAMPLE_DELAY(80); // ~80ms between samples

IMU::IMU() : i2c_fd(-1), mx(0), my(0), mz(0),
             bias_x(0), bias_y(0), bias_z(0),
             temp_bias_x(0), temp_bias_y(0), temp_bias_z(0) {}

IMU::~IMU() {
    if (i2c_fd >= 0) {
        close(i2c_fd);
    }
}

bool IMU::begin() {
    // Open I2C device
    i2c_fd = open(I2C_DEVICE, O_RDWR);
    if (i2c_fd < 0) {
        std::cerr << "IMU Error: Failed to open " << I2C_DEVICE << std::endl;
        return false;
    }

    // Select Magnetometer Address
    if (ioctl(i2c_fd, I2C_SLAVE, MAG_ADDR) < 0) {
        std::cerr << "IMU Error: Failed to acquire bus access/talk to slave" << std::endl;
        close(i2c_fd);
        i2c_fd = -1;
        return false;
    }

    // Configure Registers
    if (!writeReg(CRA_REG_M, 0x10)) return false; // data rate (15 Hz)
    if (!writeReg(CRB_REG_M, 0x20)) return false; // gain
    if (!writeReg(MR_REG_M, 0x00))  return false; // continuous mode

    // start with zero biases (in-memory only)
    bias_x = bias_y = bias_z = 0;
    temp_bias_x = temp_bias_y = temp_bias_z = 0;

    return true;
}

void IMU::update() {
    if (i2c_fd < 0) return;

    // Ensure we are talking to the Magnetometer 
    ioctl(i2c_fd, I2C_SLAVE, MAG_ADDR);

    uint8_t data[6];

    // Read 6 bytes starting from OUT_X_H_M
    if (readRegs(OUT_X_H_M, data, 6)) {
        // Registers are ordered X, Z, Y in the memory map for many HMC sensors
        // Data is Big Endian (High byte, Low byte)
        mx = (int16_t)((data[0] << 8) | data[1]); // X
        mz = (int16_t)((data[2] << 8) | data[3]); // Z
        my = (int16_t)((data[4] << 8) | data[5]); // Y
    }
}

int16_t IMU::getX() const {
    int32_t val = static_cast<int32_t>(mx) - bias_x - temp_bias_x;
    return static_cast<int16_t>(val);
}

int16_t IMU::getY() const {
    int32_t val = static_cast<int32_t>(my) - bias_y - temp_bias_y;
    return static_cast<int16_t>(val);
}

int16_t IMU::getZ() const {
    int32_t val = static_cast<int32_t>(mz) - bias_z - temp_bias_z;
    return static_cast<int16_t>(val);
}

bool IMU::calibrateNow() {
    // Read multiple samples and average to produce a stable saved bias (in-memory only)
    if (i2c_fd < 0) return false;

    int64_t sum_x = 0, sum_y = 0, sum_z = 0;
    for (int i = 0; i < CALIB_SAMPLE_COUNT; ++i) {
        update();
        sum_x += static_cast<int32_t>(mx);
        sum_y += static_cast<int32_t>(my);
        sum_z += static_cast<int32_t>(mz);
        if (i + 1 < CALIB_SAMPLE_COUNT)
            std::this_thread::sleep_for(CALIB_SAMPLE_DELAY);
    }

    int32_t avg_x = static_cast<int32_t>(sum_x / CALIB_SAMPLE_COUNT);
    int32_t avg_y = static_cast<int32_t>(sum_y / CALIB_SAMPLE_COUNT);
    int32_t avg_z = static_cast<int32_t>(sum_z / CALIB_SAMPLE_COUNT);

    // Set saved bias to the averaged raw reading so that current pose becomes "zero".
    bias_x = avg_x;
    bias_y = avg_y;
    bias_z = avg_z;

    std::cout << "IMU: Calibrated (averaged) bias set to current reading: "
              << bias_x << ", " << bias_y << ", " << bias_z << std::endl;

    // Clear any temp bias
    temp_bias_x = temp_bias_y = temp_bias_z = 0;

    return true;
}

void IMU::setTempBiasFromCurrentReading() {
    // Capture multiple samples and compute an averaged temporary bias (as a delta from saved bias)
    if (i2c_fd < 0) return;

    int64_t sum_x = 0, sum_y = 0, sum_z = 0;
    for (int i = 0; i < CALIB_SAMPLE_COUNT; ++i) {
        update();
        sum_x += static_cast<int32_t>(mx);
        sum_y += static_cast<int32_t>(my);
        sum_z += static_cast<int32_t>(mz);
        if (i + 1 < CALIB_SAMPLE_COUNT)
            std::this_thread::sleep_for(CALIB_SAMPLE_DELAY);
    }

    int32_t avg_x = static_cast<int32_t>(sum_x / CALIB_SAMPLE_COUNT);
    int32_t avg_y = static_cast<int32_t>(sum_y / CALIB_SAMPLE_COUNT);
    int32_t avg_z = static_cast<int32_t>(sum_z / CALIB_SAMPLE_COUNT);

    // Important: store temp as the delta from the currently saved bias.
    // This lets commitTempBiasToSaved() continue to add temp (saved += temp)
    // while still resulting in saved == avg_raw (the desired behavior).
    temp_bias_x = avg_x - bias_x;
    temp_bias_y = avg_y - bias_y;
    temp_bias_z = avg_z - bias_z;

    std::cout << "IMU: Temp bias set for preview (avg_raw - saved): "
              << temp_bias_x << ", " << temp_bias_y << ", " << temp_bias_z
              << "  (avg_raw: " << avg_x << "," << avg_y << "," << avg_z << ")" << std::endl;
}

void IMU::clearTempBias() {
    temp_bias_x = temp_bias_y = temp_bias_z = 0;
    std::cout << "IMU: Temp bias cleared." << std::endl;
}

bool IMU::commitTempBiasToSaved() {
    // Make the temp bias permanent by adding the delta into the saved bias, then clear temp.
    // Because temp_bias is avg_raw - saved, this results in saved := saved + (avg_raw - saved) = avg_raw
    bias_x += temp_bias_x;
    bias_y += temp_bias_y;
    bias_z += temp_bias_z;

    temp_bias_x = temp_bias_y = temp_bias_z = 0;

    std::cout << "IMU: Committed temp bias to saved bias: "
              << bias_x << ", " << bias_y << ", " << bias_z << std::endl;
    return true;
}

bool IMU::writeReg(uint8_t reg, uint8_t value) {
    uint8_t buf[2] = {reg, value};
    return write(i2c_fd, buf, 2) == 2;
}

bool IMU::readRegs(uint8_t start, uint8_t *data, int len) {
    // Write register address we want to start reading from
    if (write(i2c_fd, &start, 1) != 1) return false;
    // Read the data back
    return read(i2c_fd, data, len) == len;
}

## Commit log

2025-11-14 added imu logic and screen
2025-11-17 Added STL files for tiltgolf housing (needs edits to fit IMU + breadboard)
    [bbb_case_back_board_mount.stl, bbb_case_front_lcd_mount.stl]
2025-12-03 Added v1 housing to github
    [BackCover.stl, Button.stl, FrontCover.stl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]
2025-12-05 sensor reading sync and level2 design
2025-12-06 Qt repaint every frame
2025-12-07 bugfixes and styling edits to level 3 and shrank hole size for the rest
    [LevelData.h]
2025-12-07 styling fixes to world size & level 2
    [LevelData.h]
2025-12-07 level 6 fixes to sstyling
    [LevelData.h]
2025-12-08 tiltgolf_noah13 is the current working level 1-6
2025-12-08 level lock and free play button
2025-12-08 bugfix change button to main menu when in free play menu
2025-12-08 Added final housing STLs & and tiltgolf_noah18 is the executable to use
    [backcovernew.stl, frontcovernew.stl, leftcovernew.stl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]
2025-12-10 added beaglebone holder STL file
    [bbbholder.stl]
2025-12-10 IMU edits
2025-12-10 added a couple of images
